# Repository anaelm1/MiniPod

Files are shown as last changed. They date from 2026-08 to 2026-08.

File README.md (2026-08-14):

# MiniPod 

MiniPod is a simple MP3 player which functions using the Arduino Nano, and even has an OLED Display. It has an Audio Jack for the output and plays songs from a MicroSD card. 

It is made so that I can listen to songs offline and without the distractions of a Smartphone in environments like the GYM. It is inspired by the Apple Ipod.

## Features:
- 3D printed body with 6 buttons for controls. 
- 128x32 OLED Display to display current song and artists.
- 6 controls (Pause/Play, Previous, Next, Vol up, Vol down).
- Usb C charging port

## CAD Model:
The pcb is attached to the base at a height of 5mm using 4 M3 screws to have enough space for the battery. The top plate is attached to the body using smaller M1 screws and heat inserts due to narrow walls. 

It has 8 separate printed pieces. The base where the PCB sits, the top cover, the 6 hand made buttons, and the side power button. The project and my name is embossed on the top plate as well.

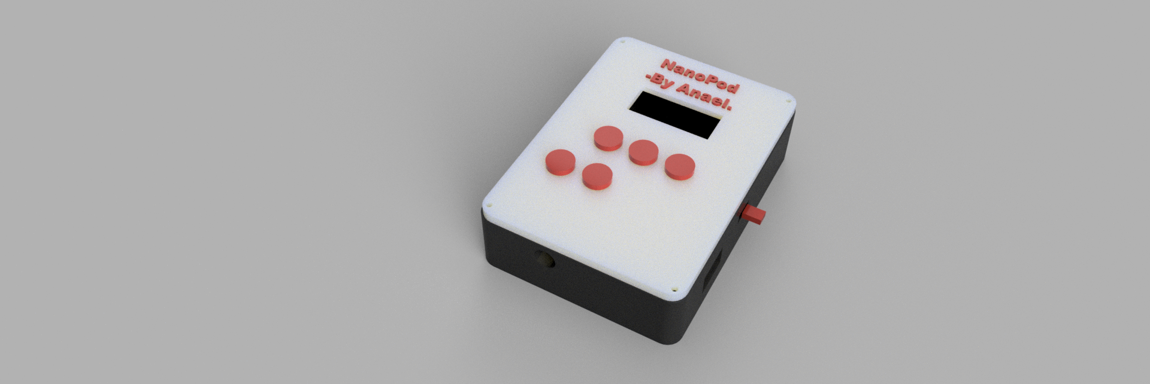
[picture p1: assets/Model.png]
Model


Made in Fusion360. 

## PCB
Here's my PCB! It was made in KiCad. The components are placed on both sides of the PCB to save space.

Schematic
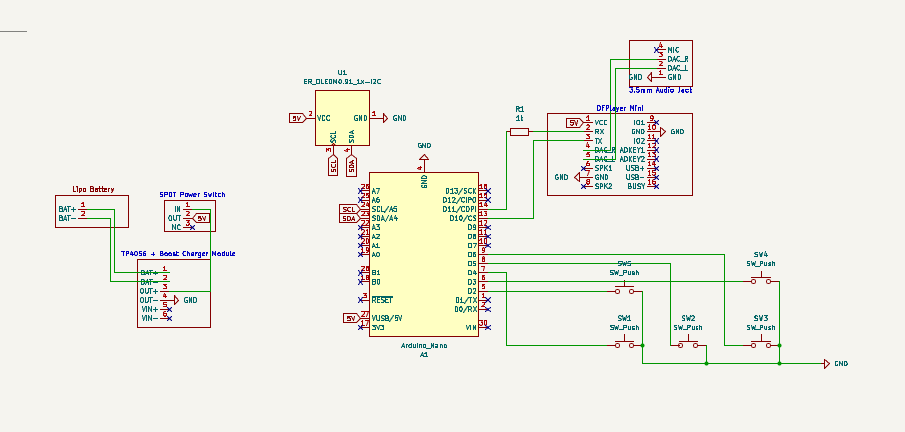
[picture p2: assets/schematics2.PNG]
Schematic


PCB
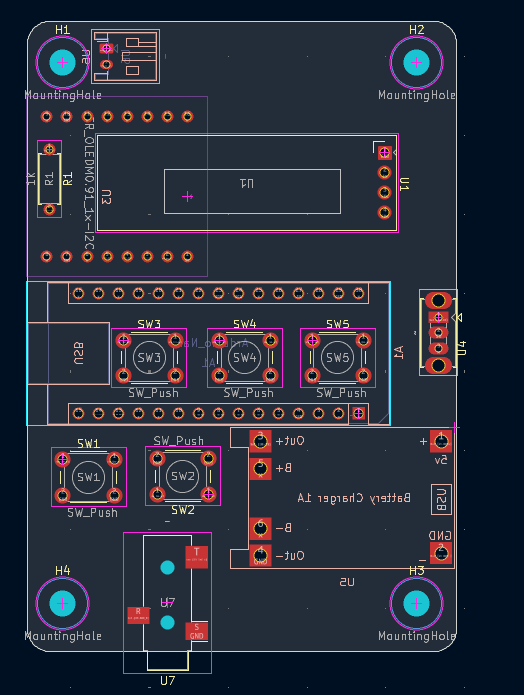
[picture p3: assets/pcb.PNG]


## Firmware Overview
MiniPod uses two programs for firmware. 

-A python script which renames all songs into simple indexes (000-999), so that they can be easily accesed by the DFPlayer Mini. It also creates a csv file linking all indexes to their song names.

-The main Ardunio script written in C which runs the MiniPod and all its functions. (I used C, because I learned it a few months ago while doing Harvards CS50x).

- The buttons will be hand labelled. 
- There is Vol up and Vol down option as well. 
- The OLED is the song name, artist name, index, and playing status.

## AI Usage:
While I tried to keep AI usage minimum, it was used for these things: 

-All the research and finalization of the components.

-Fusion360 controls help

-Major help in the Ardunio part of the firmware. I tried to not copy paste any code at all, at least not without understanding it first. 

## MicroSD Card Format

Your MicroSD card must be formatted to **FAT16/FAT32** and contain an `index.csv` file in the root folder using the following format:

csv

Index,Title,Artist

000,Bohemian Rhapsody,Queen

001,Hotel California,Eagles

002,Billie Jean,Michael Jackson

## BOM:
These are the components used in the GamePad 9:

-Arduino Nano

-DFPlayer Mini MP3 Audio Player Module

-TRRS Module PJ-320A 3.5mm Female Audio Jack Connector

-0.96 inch I2C SSD1306 128x64 OLED Display Module

-3.7V LiPo Battery 

-TP4056 + Boost Charger Module

-SPDT Power Switch

-5 Tactile Switch 6x6

-1k Ohm Resistor

-2 2.54mm Single Row Female Pin Header Strip

-2 2.54mm Single Row Male Pin Header Strip

-M1.6 Heat-Set Brass Inserts

-M1.6 Machine Screws

-M3 Screws

-3D printed body

## Info
This is my first solo hardware project. Please let me know if you spot any kind a flaw!

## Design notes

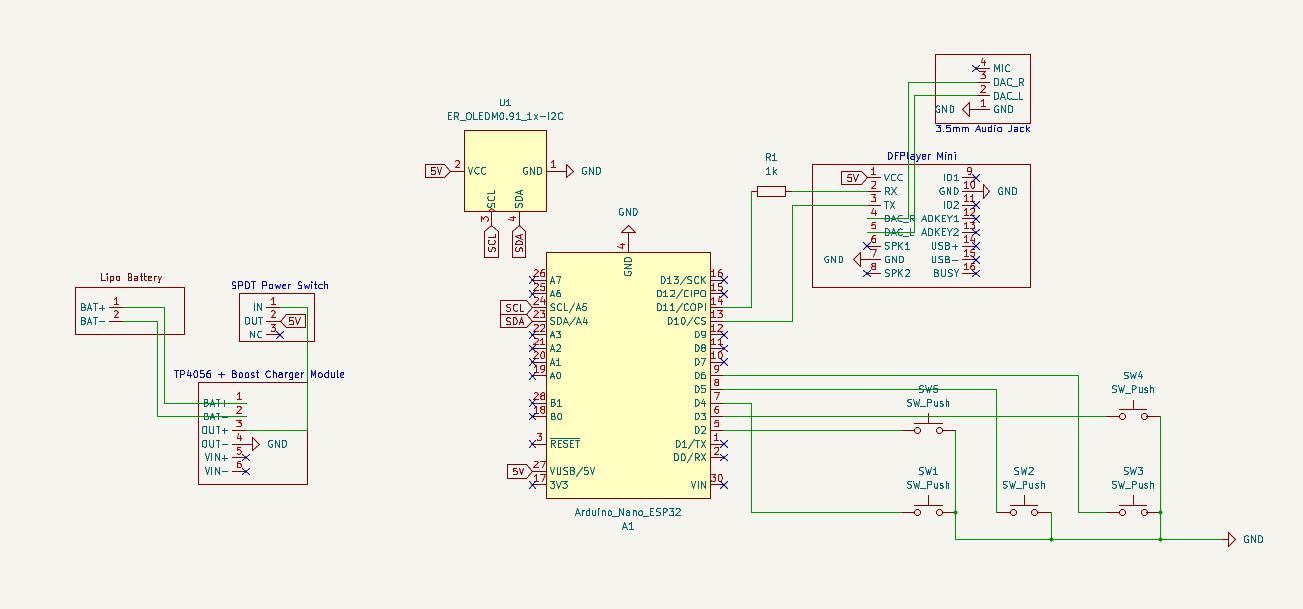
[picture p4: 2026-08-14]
assets/schematics.PNG

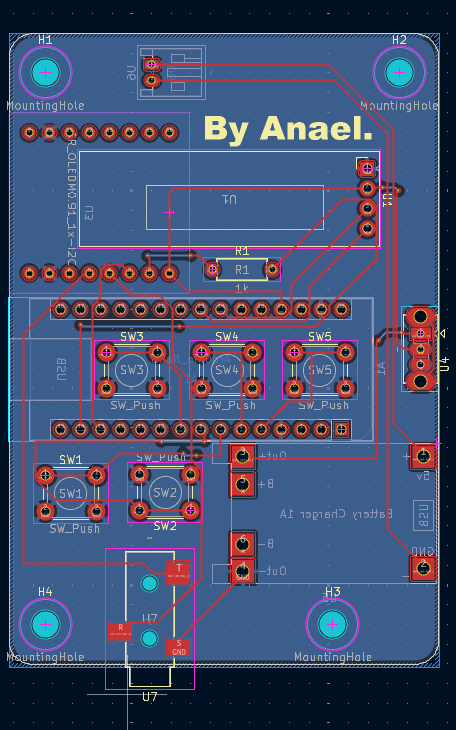
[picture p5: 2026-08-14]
assets/finalpcb.PNG

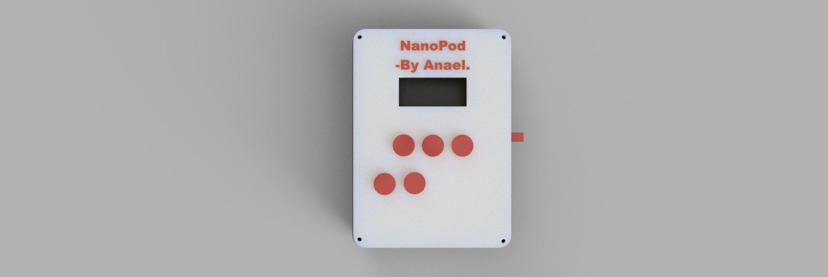
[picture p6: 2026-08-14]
assets/Model2.png

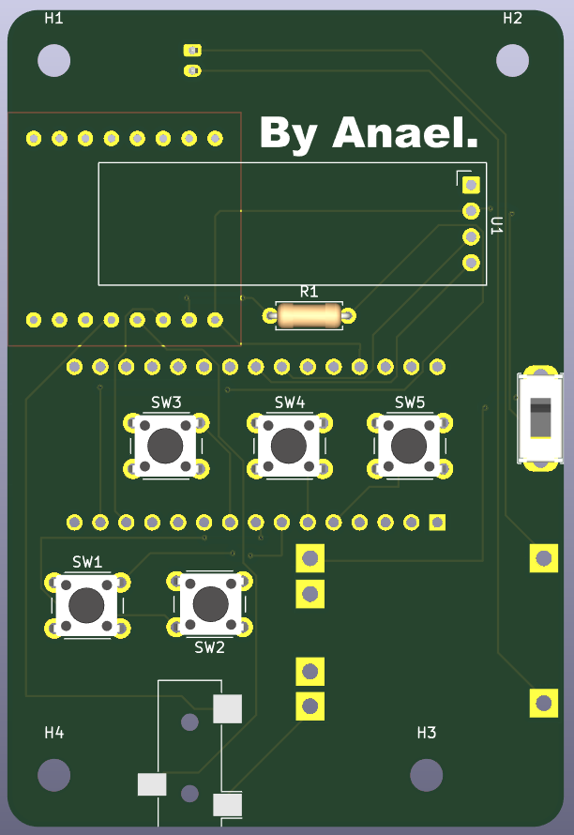
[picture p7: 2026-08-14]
assets/pcb 3d.PNG

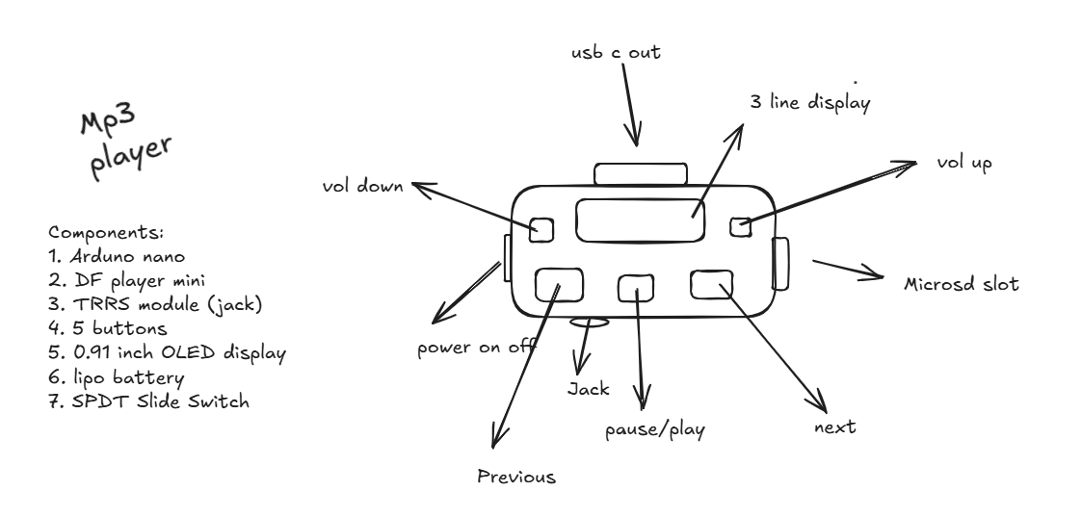
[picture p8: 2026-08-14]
assets/planning.PNG

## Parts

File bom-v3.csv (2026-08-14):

Item # | Component / Name | Description / Specification | Category | Pack / Purchase Qty | Total Price (USD)
1 | Arduino Nano | ATmega328P Microcontroller Board (CH340G) | Microcontroller | 1 Pc | 3.2
2 | DFPlayer Mini MP3 Audio Player Module | UART Hardware Audio Decoder / MicroSD Card Slot | Audio Module | 1 Pc | 1.4
3 | TRRS Module PJ-320A 3.5mm Female Audio Jack Connector | 3.5mm PCB Mount Audio Jack Module | Connector | Pack of 5 | 1.2
4 | 0.96 inch I2C SSD1306 128x64 OLED Display Module | Monochrome 128x64 OLED Screen, I2C Interface | Display | 1 Pc | 1.8
5 | 3.7V LiPo Battery | Rechargeable 3.7V Lithium Polymer Battery (1S) | Power | 1 Pc | 2.8
6 | TP4056 + Boost Charger Module | 1S LiPo Charger with 5V Step-Up Boost Output | Power / Charger | Pack of 5 | 2.2
7 | SPDT Power Switch | SS12D00 Mini Slide Switch (3-pin, SPDT) | Switch | Pack of 20 | 0.9
8 | Tactile Switch 6x6 | 6x6x5mm Momentary Push Button Switch | Switch | Pack of 50 | 1.1
9 | 1k Ohm Resistor | 1/4W Metal Film Resistors 1kΩ | Passive Component | Pack of 100 | 1.0
10 | 2.54mm Single Row Female Pin Header Strip | 40-pin 2.54mm pitch female socket strips | Connector / Header | Pack of 10 | 1.2
11 | 2.54mm Single Row Male Pin Header Strip | 40-pin 2.54mm pitch male pin headers | Connector / Header | Pack of 10 | 0.8
12 | M1.6 Heat-Set Brass Inserts | M1.6 Threaded Brass Heat-Set Inserts | Hardware | Pack of 50 | 1.5
13 | M1.6 Machine Screws | M1.6 Pan Head Metric Machine Screws | Hardware | Pack of 50 | 1.3
14 | M3 Screws | M3 Metric Button/Pan Head Machine Screws | Hardware | Pack of 50 | 1.6
15 | Custom 3D printed Body | Body1 - Printed by Printing Legion (Filament + Shipping) | Enclosure | 1 Unit | 10.0
16 | Custom PCB board | Board1 - Fabricated PCB from JLCPCB (Preparation + Shipping) | PCB | 1 Order (5 Pcs) | 18.0

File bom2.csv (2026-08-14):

Item # | Component / Name | Description / Specification | Category | Quantity | Estimated Unit Price (USD) | Estimated Total Price (USD)
1 | Arduino Nano | ATmega328P Microcontroller Board | Microcontroller | 1 | 4.5 | 4.5
2 | DFPlayer Mini MP3 Audio Player Module | UART Hardware Audio Decoder / MicroSD Module | Audio Module | 1 | 1.8 | 1.8
3 | TRRS Module PJ-320A 3.5mm Female Audio Jack Connector | 3.5mm PCB Mount Headphone Jack Connector | Connector | 1 | 0.3 | 0.3
4 | 0.96 inch I2C SSD1306 128x64 OLED Display Module | Monochrome OLED Display, I2C Interface | Display | 1 | 2.2 | 2.2
5 | 3.7V LiPo Battery | Rechargeable Lithium Polymer Battery (1S) | Power | 1 | 2.5 | 2.5
6 | TP4056 + Boost Charger Module | 1S LiPo Charger with 5V Step-Up Converter | Power / Charger | 1 | 1.2 | 1.2
7 | SPDT Power Switch | Single Pole Double Throw Slide Switch | Switch | 1 | 0.15 | 0.15
8 | Tactile Switch 6x6 | 6x6mm Momentary Push Button Switch | Switch | 5 | 0.05 | 0.25
9 | 1k Ohm Resistor | 1kΩ 1/4W Through-Hole / SMD Resistor | Passive Component | 1 | 0.02 | 0.02
10 | 2.54mm Single Row Female Pin Header Strip | 15-pin 2.54mm pitch female socket connector | Connector / Header | 2 | 0.15 | 0.3
11 | 2.54mm Single Row Male Pin Header Strip | 15-pin 2.54mm pitch male pin header | Connector / Header | 2 | 0.1 | 0.2
12 | M1.6 Heat-Set Brass Inserts | Threaded brass inserts for 3D printed housing | Hardware | 4 | 0.1 | 0.4
13 | M1.6 Machine Screws | M1.6 Pan Head Machine Screws for mounting PCB/modules | Hardware | 4 | 0.05 | 0.2
14 | M3 Screws | M3 Machine Screws for enclosure assembly | Hardware | 4 | 0.08 | 0.32
15 | 3D printed body | Custom 3D printed Body | Body | 1 | Printed by printing legion | 10 usd(filament + shipping)
16 | Custom PCB board | PCB board from JLCPCB | Board | 1 | 18 usd | 18 usd (preperation + shipping)

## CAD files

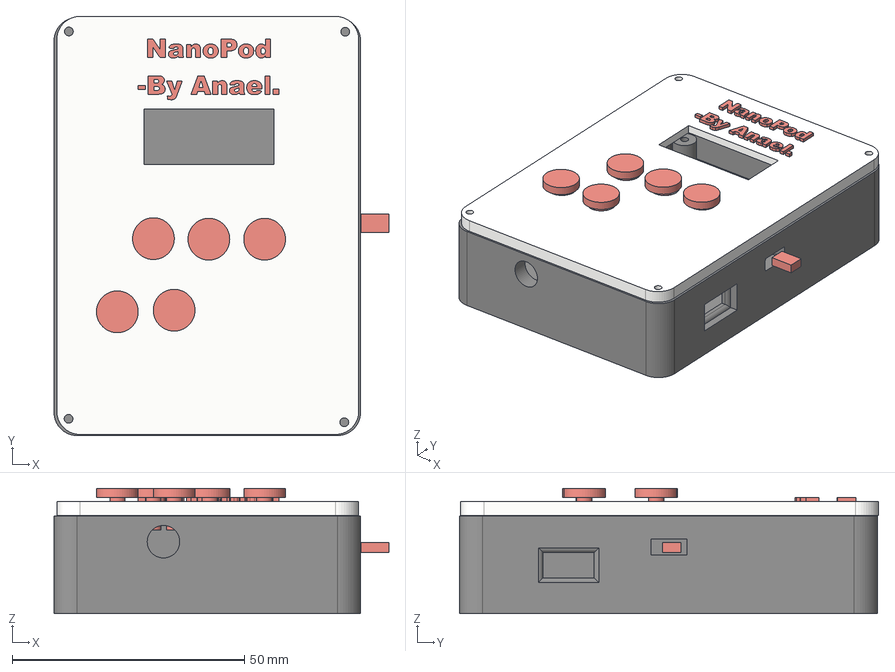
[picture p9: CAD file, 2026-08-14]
CAD/Whole_body.step
72.1 x 90.2 x 27.0 mm

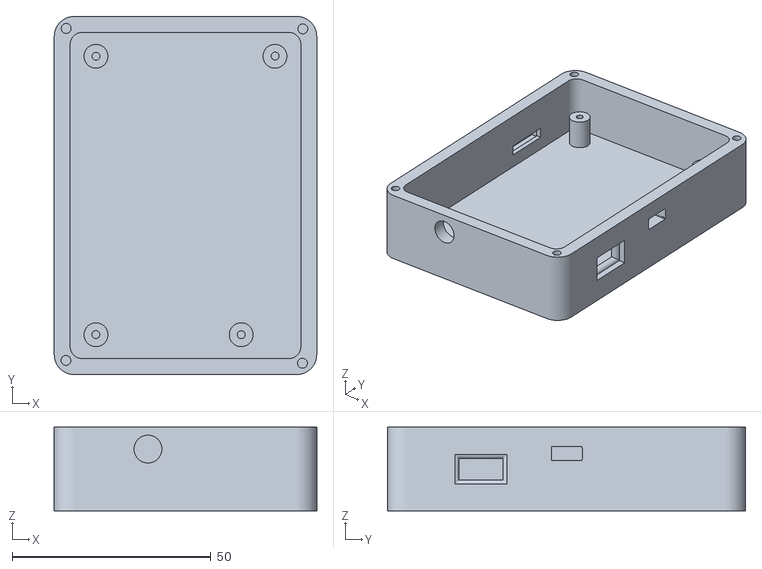
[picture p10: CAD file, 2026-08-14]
production/Body.stl
66.0 x 90.0 x 21.0

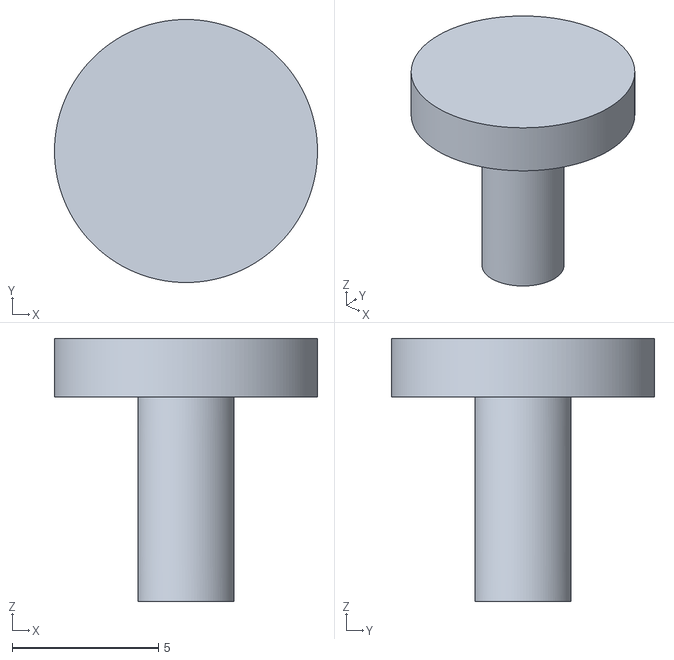
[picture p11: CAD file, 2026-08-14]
production/Button1.stl
9.00 x 9.00 x 9.00

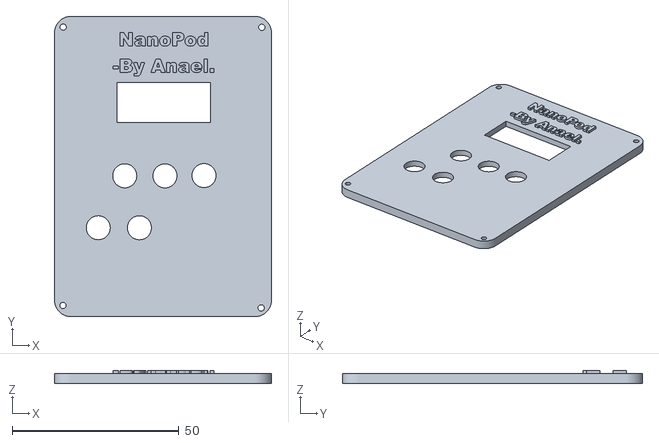
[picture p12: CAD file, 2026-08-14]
production/Top.stl
65.0 x 90.0 x 3.80

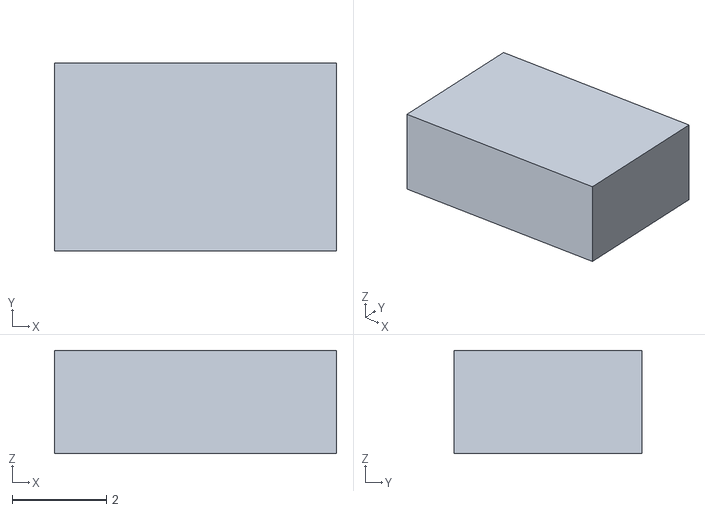
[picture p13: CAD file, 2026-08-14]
production/Sidebutton.stl
6.00 x 4.00 x 2.20

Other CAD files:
production/Button4.stl
production/Button3.stl
production/Button2.stl
production/Buttton5.stl

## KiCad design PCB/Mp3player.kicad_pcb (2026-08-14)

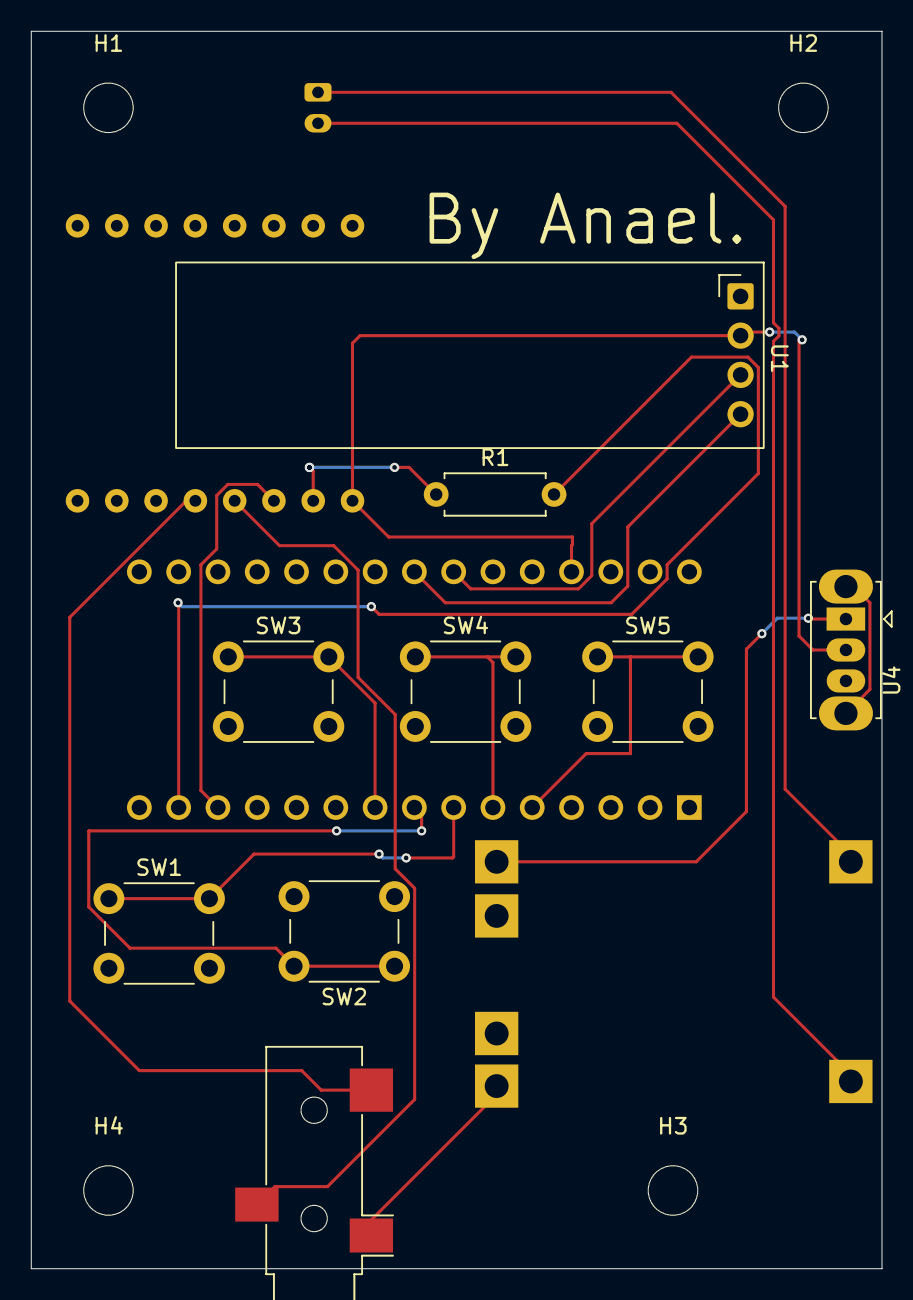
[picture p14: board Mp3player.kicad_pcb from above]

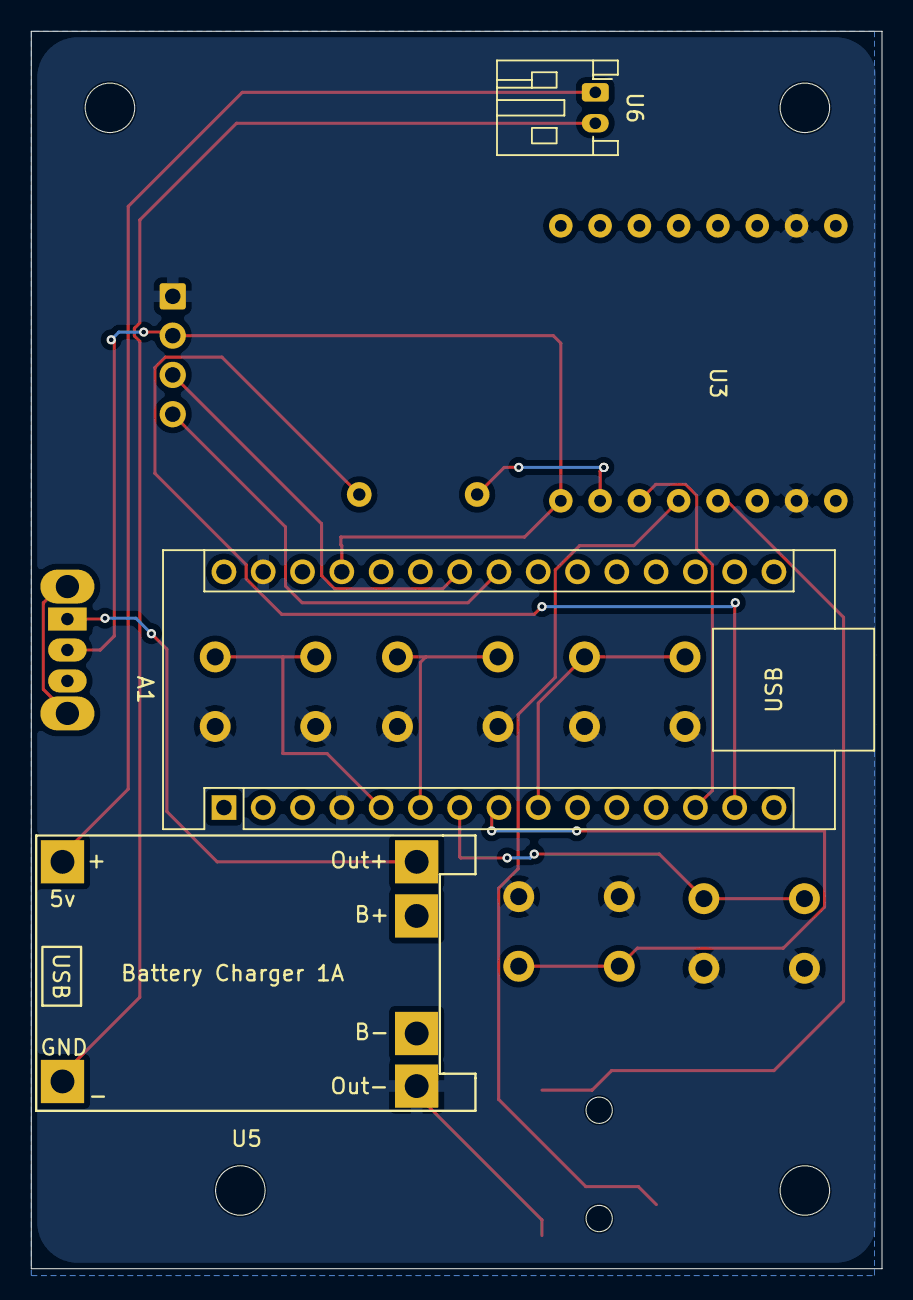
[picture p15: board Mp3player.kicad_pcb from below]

Board: 2 copper layers, 55.0 x 80.0 mm, 17 parts (4 on the bottom side), 17 nets.

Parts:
A1: Arduino_Nano
H1, H2, H3, H4: MountingHole; MountingHole_3.2mm_M3
R1: 1k; R_Axial_DIN0207_L6.3mm_D2.5mm_P7.62mm_Horizontal
SW1, SW2, SW3, SW4, SW5: SW_Push; SW_PUSH_6mm_H5mm
U1: ER_OLEDM0.91_1x-I2C
U3: DFPlayer
U4: SW_Slide_SPDT_Straight_CK_OS102011MS2Q
U5: TP4056-18650
U6: JST_PH_S2B-PH-K_1x02_P2.00mm_Horizontal
U7: Jack_3.5mm_CUI_SJ-3523-SMT_Horizontal

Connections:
5V: A1.27 (VUSB/5V), U1.2 (VCC), U3.1 (VCC), U4.2 (OUT)
GND: A1.4 (GND), A1.29 (GND), SW1.2, SW2.2, SW3.2, SW4.2, SW5.2, U1.1 (GND), U3.7 (GND), U3.10 (GND), U5.4 (OUT-), U7.S (GND)
unnamed: A1.5 (D2), SW5.1
unnamed: A1.6 (D3), SW4.1
unnamed: A1.7 (D4), SW1.1
unnamed: A1.8 (D5), SW2.1
unnamed: A1.9 (D6), SW3.1
unnamed: A1.13 (D10/CS), U3.3 (TX)
unnamed: A1.14 (D11/COPI), R1.2
unnamed: U3.5 (DAC_L), U7.T (DAC_L)
unnamed: U3.4 (DAC_R), U7.R (DAC_R)
unnamed: R1.1, U3.2 (RX)
unnamed: U4.1 (IN), U5.3 (OUT+)
unnamed: U5.1 (BAT+), U6.1 (BAT+)
unnamed: U5.2 (BAT-), U6.2 (BAT-)
SCL: A1.24 (SCL/A5), U1.3 (SCL)
SDA: A1.23 (SDA/A4), U1.4 (SDA)

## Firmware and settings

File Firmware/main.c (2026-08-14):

// Chunks especially the pin management of this file is written by Gemini

#include <stdio.h>
#include <stdlib.h>
#include <string.h>
#include <SPI.h>
#include <SD.h>
#include <Adafruit_GFX.h>
#include <Adafruit_SSD1306.h>
#include <SoftwareSerial.h>

#define SCREEN_WIDTH  128
#define SCREEN_HEIGHT 64
#define OLED_RESET    -1 // Reset pin (-1 if sharing Arduino reset pin)

// Create screen instance (0x3C is standard I2C address for SSD1306)
Adafruit_SSD1306 display(SCREEN_WIDTH, SCREEN_HEIGHT, &Wire, OLED_RESET);

// RX Pin 8, TX Pin 9 (TX connects to MP3 RX pin via a 1k resistor)
SoftwareSerial mp3Serial(8, 9);

const int SD_CS_PIN = 10; // pin config for SD CS

// Global Variables
int currentTrackIndex = 0;
int isPlaying = 0; // 1 is playing, 0 is not playing
int total_tracks = 0; 
int currentVolume = 15;
const int MIN_VOLUME = 0;
const int MAX_VOLUME = 30;

struct Data {
    char title[22]; // max characters shown by the screen are 21
    char artist[22]; // max characters shown by the screen are 21
    char index[16]; // Thats how many we need
};

// Prototypes for funcs
void count_total_tracks(const char *filename, int *total_tracks_ptr);
struct Data track_details(int index);
void next_track(int *currentTrackIndex_ptr);
void prev_track(int *currentTrackIndex_ptr);
void pause_play(int *playing_ptr);
void volume_up(int *volume_ptr);
void volume_down(int *volume_ptr);
void send_mp3_command(uint8_t command, uint16_t parameter);
void mp3_play_track(int trackIndex);
void mp3_pause();
void mp3_resume();
void mp3_set_volume(int volume);
void render_screen(struct Data track, int is_playing, int current_vol, int total);

const int NEXT_PIN       = 6;
const int PREV_PIN       = 4;
const int PLAY_PAUSE_PIN = 5;
const int VOL_UP_PIN     = 2;
const int VOL_DOWN_PIN   = 3;

// Timers for Debouncing
unsigned long lastDebounceTime = 0;
const unsigned long DEBOUNCE_DELAY = 150; // Milliseconds to wait between button reads

void setup_pins() {
    // Configure pins as inputs with internal pullup resistors.
    // When the button is NOT pressed pin reads HIGH (1).
    // When the button IS pressed (connected to Ground) pin reads LOW (0).
    pinMode(NEXT_PIN, INPUT_PULLUP);
    pinMode(PREV_PIN, INPUT_PULLUP);
    pinMode(PLAY_PAUSE_PIN, INPUT_PULLUP);
    pinMode(VOL_UP_PIN, INPUT_PULLUP);
    pinMode(VOL_DOWN_PIN, INPUT_PULLUP);
}

void setup_display() {
    // 0x3C is the default I2C address for 0.96" OLEDs
    if (!display.begin(SSD1306_SWITCHCAPVCC, 0x3C)) {
        Serial.println(F("SSD1306 allocation failed"));
        for (;;); // Don't proceed, loop forever if display isn't wired
    }
    
    display.clearDisplay();
    display.setTextColor(SSD1306_WHITE);
    display.setTextSize(1);
    display.setCursor(10, 25);
    display.println("MP3 PLAYER BOOTING");
    display.display(); // Sends the RAM buffer to the physical screen
}

void setup() {
    // Start hardware Serial
    Serial.begin(115200);
    while (!Serial) { ; } // Wait for serial console to open

    Serial.println("Booting MiniPod Firmware...");

    setup_pins();
    setup_display();
    mp3Serial.begin(9600);
    delay(500);
    mp3_set_volume(currentVolume);

    // Initialize physical SD card hardware
    if (!SD.begin(SD_CS_PIN)) {
        Serial.println("Error: SD Card Initialization Failed!");
        return;
    }
    Serial.println("SD Card Initialized successfully.");

    // Count available songs on the SD card during startup
    count_total_tracks("index.csv", &total_tracks);
    Serial.print("Total Tracks Found: ");
    Serial.println(total_tracks);

    // Fetch details for the first track (Index 0)
    struct Data initialTrack = track_details(currentTrackIndex);
    Serial.print("Initial Track: ");
    Serial.println(initialTrack.title);
    
    render_screen(initialTrack, isPlaying, currentVolume, total_tracks);
}

void check_buttons() {
    unsigned long currentMillis = millis();

    if (currentMillis - lastDebounceTime > DEBOUNCE_DELAY) {
        bool state_changed = false;

        // 1. Next Track
        if (digitalRead(NEXT_PIN) == LOW) {
            next_track(&currentTrackIndex);
            mp3_play_track(currentTrackIndex); // Send UART Command to Module
            isPlaying = 1;
            state_changed = true;
        } 
        // 2. Previous Track
        else if (digitalRead(PREV_PIN) == LOW) {
            prev_track(&currentTrackIndex);
            mp3_play_track(currentTrackIndex); // Send UART Command to Module
            isPlaying = 1;
            state_changed = true;
        } 
        // 3. Play / Pause Toggle
        else if (digitalRead(PLAY_PAUSE_PIN) == LOW) {
            pause_play(&isPlaying);
            if (isPlaying) {
                mp3_resume();
            } else {
                mp3_pause();
            }
            state_changed = true;
        } 
        // 4. Volume Up
        else if (digitalRead(VOL_UP_PIN) == LOW) {
            volume_up(&currentVolume);
            mp3_set_volume(currentVolume); // Send UART Volume Command
            state_changed = true;
        } 
        // 5. Volume Down
        else if (digitalRead(VOL_DOWN_PIN) == LOW) {
            volume_down(&currentVolume);
            mp3_set_volume(currentVolume); // Send UART Volume Command
            state_changed = true;
        }

        // Re-render UI frame on OLED display
        if (state_changed) {
            struct Data current_track = track_details(currentTrackIndex);
            render_screen(current_track, isPlaying, currentVolume, total_tracks);
            lastDebounceTime = currentMillis;
        }
    }
}

void render_screen(struct Data track, int is_playing, int current_vol, int total) {
    display.clearDisplay(); // Always clear previous frame first!

    // --- Line 1: Header (Track position & Volume) ---
    display.setTextSize(1);
    display.setCursor(0, 0);
    // Print formatted track position: e.g. [001/012]
    display.print("[");
    display.print(track.index);
    display.print("/");
    if (total < 10) display.print("0");
    if (total < 100) display.print("0");
    display.print(total);
    display.print("] ");

    // Print volume on top right
    display.setCursor(80, 0);
    display.print("Vol:");
    display.print(current_vol);

    // --- Divider Line ---
    display.drawLine(0, 10, 128, 10, SSD1306_WHITE);

    // --- Line 2: Track Title ---
    display.setCursor(0, 16);
    display.setTextSize(1); // Fits up to 21 characters
    display.print(track.title);

    // --- Line 3: Artist Name ---
    display.setCursor(0, 32);
    display.print(track.artist);

    // --- Divider Line ---
    display.drawLine(0, 48, 128, 48, SSD1306_WHITE);

    // --- Line 4: Play / Pause Status ---
    display.setCursor(0, 52);
    if (is_playing) {
        display.print("Status: PLAYING >");
    } else {
        display.print("Status: PAUSED ||");
    }

    // Refresh the physical display hardware with new buffer data
    display.display(); 
}

// Helper function to send raw 10-byte command packets to the MP3 module
void send_mp3_command(uint8_t command, uint16_t parameter) {
    // Calculate 16-bit Checksum required by the module protocol
    uint16_t checksum = -(0xFF + 0x06 + command + 0x01 + (uint8_t)(parameter >> 8) + (uint8_t)parameter);

    // Build the 10-byte array
    uint8_t commandPacket[10] = {
        0x7E,                           // Start Byte
        0xFF,                           // Version
        0x06,                           // Length
        command,                        // Command Code (e.g. 0x03 for Play Track)
        0x01,                           // Feedback required
        (uint8_t)(parameter >> 8),      // Parameter High Byte
        (uint8_t)(parameter & 0xFF),    // Parameter Low Byte
        (uint8_t)(checksum >> 8),       // Checksum High Byte
        (uint8_t)(checksum & 0xFF),     // Checksum Low Byte
        0xEF                            // End Byte
    };

    // Transmit all 10 bytes sequentially over the serial pipeline
    for (int i = 0; i < 10; i++) {
        mp3Serial.write(commandPacket[i]);
    }
}

void loop() {
    // Continuously check hardware buttons
    check_buttons();
}

void count_total_tracks(const char *filename, int *total_tracks_ptr) {
    File file = SD.open(filename, FILE_READ);
    if (!file) {
        *total_tracks_ptr = 0; // Dereference pointer value is 0
        return;
    }

    int count = 0;

    // Skip the header row
    if (file.available()) {
        file.readStringUntil('\n');
        while (file.available()) {
            file.readStringUntil('\n');
            count++;
        }
    }

    file.close();

    // Store count back via pointer    
    *total_tracks_ptr = count;
}

struct Data track_details(int index){
    struct Data info;
    char title[22] = "Unknown";
    char artist[22] = "Unknown";
    char target_index[16];
    sprintf(target_index, "%03d", index);

    strncpy(info.title, title, sizeof(info.title) - 1);
    strncpy(info.artist, artist, sizeof(info.artist) - 1);
    strncpy(info.index, target_index, sizeof(info.index) - 1);
    
    info.title[sizeof(info.title) - 1] = '\0';
    info.artist[sizeof(info.artist) - 1] = '\0';
    info.index[sizeof(info.index) - 1] = '\0';

    File Details = SD.open("index.csv", FILE_READ);
    if (!Details){
        strncpy(info.title, "SD CARD NOT FOUND.", sizeof(info.title) - 1);
        return info;
    }

    while (Details.available()) {
        String line = Details.readStringUntil('\n');
        line.trim();

        char buffer[128];
        line.toCharArray(buffer, sizeof(buffer));

        char *file_index = strtok(buffer, ","); // dividing data based on commas

        if (file_index != NULL && strcmp(file_index, target_index) == 0){
            char *file_title = strtok(NULL, ",");
            char *file_artist = strtok(NULL, ",");
            if (file_title) strncpy(info.title, file_title, sizeof(info.title) - 1);
            if (file_artist) strncpy(info.artist, file_artist, sizeof(info.artist) - 1);
            strncpy(info.index, file_index, sizeof(info.index) - 1);
            break;
        }
    }
    Details.close();
    return info;
}

void next_track(int *currentTrackIndex_ptr){
    *currentTrackIndex_ptr = (*currentTrackIndex_ptr + 1) % total_tracks;
}

void prev_track(int *currentTrackIndex_ptr){
    if ((*currentTrackIndex_ptr - 1) < 0){
        *currentTrackIndex_ptr = total_tracks - 1;
    }
    else{
        *currentTrackIndex_ptr = *currentTrackIndex_ptr - 1;
    }
}

void pause_play(int *playing_ptr){
    *playing_ptr = !(*playing_ptr);
}

void volume_up(int *volume_ptr) {
    if (*volume_ptr < MAX_VOLUME) {
        *volume_ptr += 1;
    }
}

void volume_down(int *volume_ptr) {
    if (*volume_ptr > MIN_VOLUME) {
        *volume_ptr -= 1;
    }
}

// Play specific track index (e.g., track index 0 becomes file 000.mp3 or track #1)
void mp3_play_track(int trackIndex) {
    // Command 0x03 = Play Track by Index Number (1-based index: track 0 is file 001.mp3)
    send_mp3_command(0x03, trackIndex + 1); 
}

// Pause audio playback
void mp3_pause() {
    send_mp3_command(0x0E, 0); // Command 0x0E = Pause
}

// Resume audio playback
void mp3_resume() {
    send_mp3_command(0x0D, 0); // Command 0x0D = Play / Resume
}

// Set Hardware Volume (0 to 30)
void mp3_set_volume(int volume) {
    send_mp3_command(0x06, volume); // Command 0x06 = Set Volume
}

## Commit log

2026-08-14 New repo
    [Body.stl, Button1.stl, Button2.stl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]
2026-08-14 Expand README with project details and specifications
    Added detailed project description, features, CAD model, PCB information, firmware overview, AI usage, MicroSD card format, BOM, and project info.
2026-08-14 Update and rename bom-v2.csv to bom2.csv
    [bom2.csv]
